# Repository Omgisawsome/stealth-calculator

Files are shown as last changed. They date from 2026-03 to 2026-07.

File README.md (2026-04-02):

Stealth Calculator- A Casio calculator with a Raspberry Pi put inside!

IMPORTANT NOTE FOR REVIEWERS, I ACCIDENTALLY PUT THIS AS TIER 2 WHEN IT'S A TIER 3 PROJECT THAT HAS A TOTAL COST OF $94.48 USD!

What is the project?

My stealth calculator is a calculator (Casio FX-991ESPLUS2), with the insides completely gutted out. Inside, it holds a Raspberry Pi Zero 2W as the main brain and a Raspberry Pi Pico 2 as a dedicated input controller. It utilizes matrix scanning to scan the custom PCB's rows and columns waiting for an input, and has the buttons mapped out. It has a 2.4 colour OLED touchscreen for easy usage and an integrated camera that's low profile, which allows the calculator to view the world, allowing for more functionality later on if I want to add other features.

How do I use it?

The device functions as a standard calculator, but by entering a special code (not sure what this will be I need to have the physical Pi to mess around with it), the user will switch from the standard Casio interface to a fully seperate menu. They may then use the integrated camera to take a photo of a math problem to recieve homework help, which is processed via the Gemini AI API to send the answers back to the calculator. It has built in WIFI, so to use at school you can just connect to your phone's hotspot for the best connection. It also constantly pulls updates from the repo, so you just need to clone it once, then it will update every few minutes (or longer depending if you want my new feature releases).

How do you build this yourself?

Just order all the parts on my BOM, and also order the PCB files. Unscrew open the calculator, and you will be able to lift off the board and the attached screen.

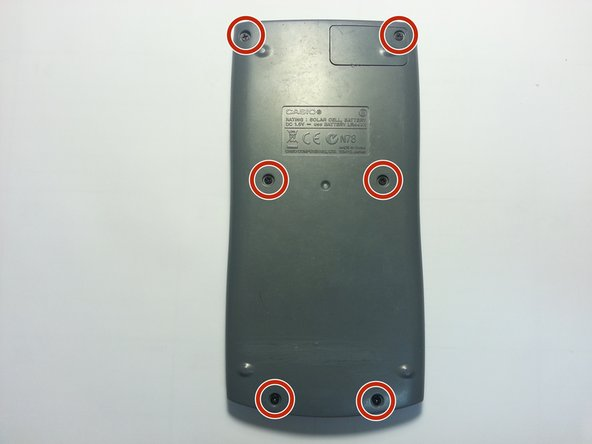
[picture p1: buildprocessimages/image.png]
Screws

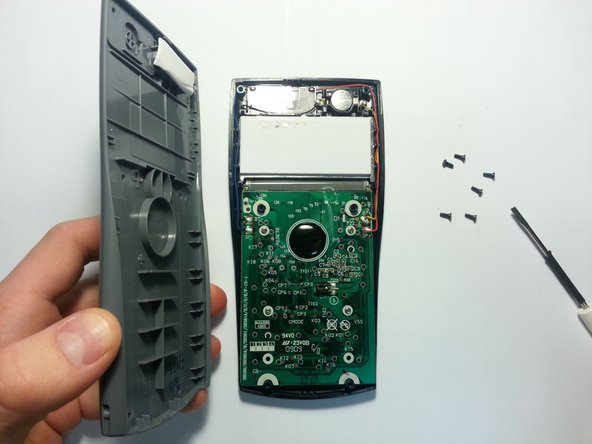
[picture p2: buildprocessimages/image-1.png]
Open Back Cover


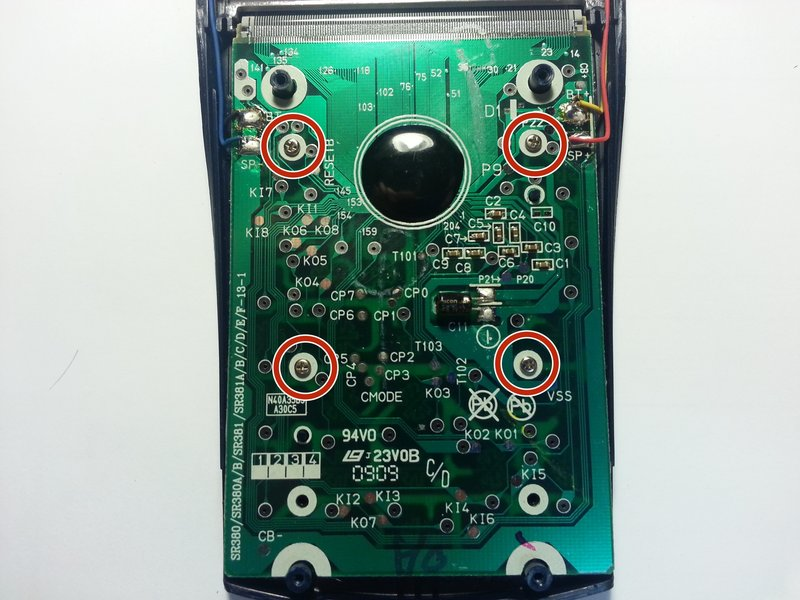
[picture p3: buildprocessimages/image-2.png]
Remove Plastic Pieces


In the calculator found in the BOM (these photos are from the web), the circled screws are actually hard pieces of plastic you have to snap. Aggresively pry the board out without breaking anything below (snap the board idc).

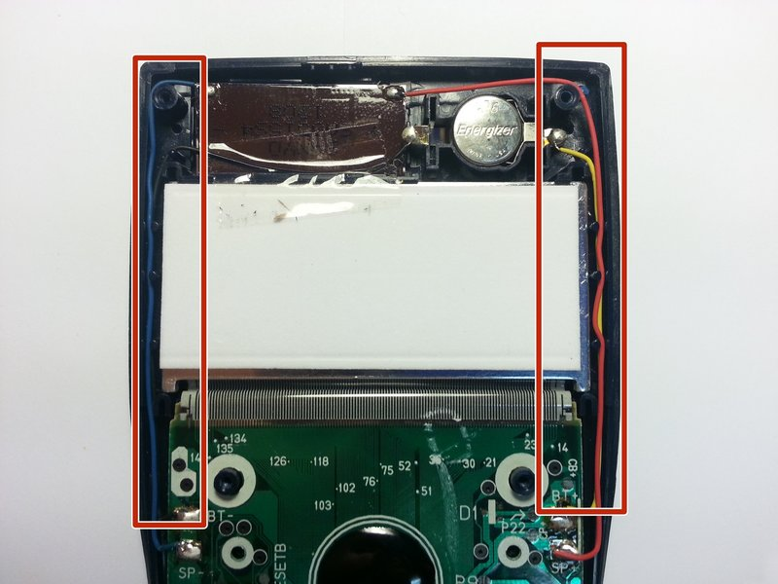
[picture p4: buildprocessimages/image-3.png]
Yank out all the guts


I really don't care if you break the PCB or screen or anything, just make sure to save this conductive rubber pad:

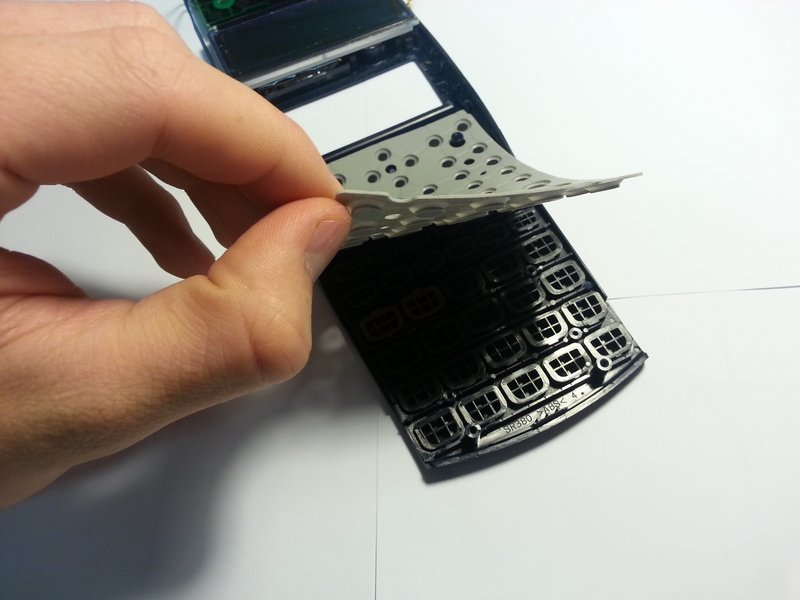
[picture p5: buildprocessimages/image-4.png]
Pad


Oh also make sure the buttons don't fall out that will irritate you (I did this myself it's so annoying).

All that should be saved is the solar panel from the top (to glue back in place), the buttons, the pad, and the top shell half and bottom shell half.

Your parts should look something like this (don't lose the screws like I did)

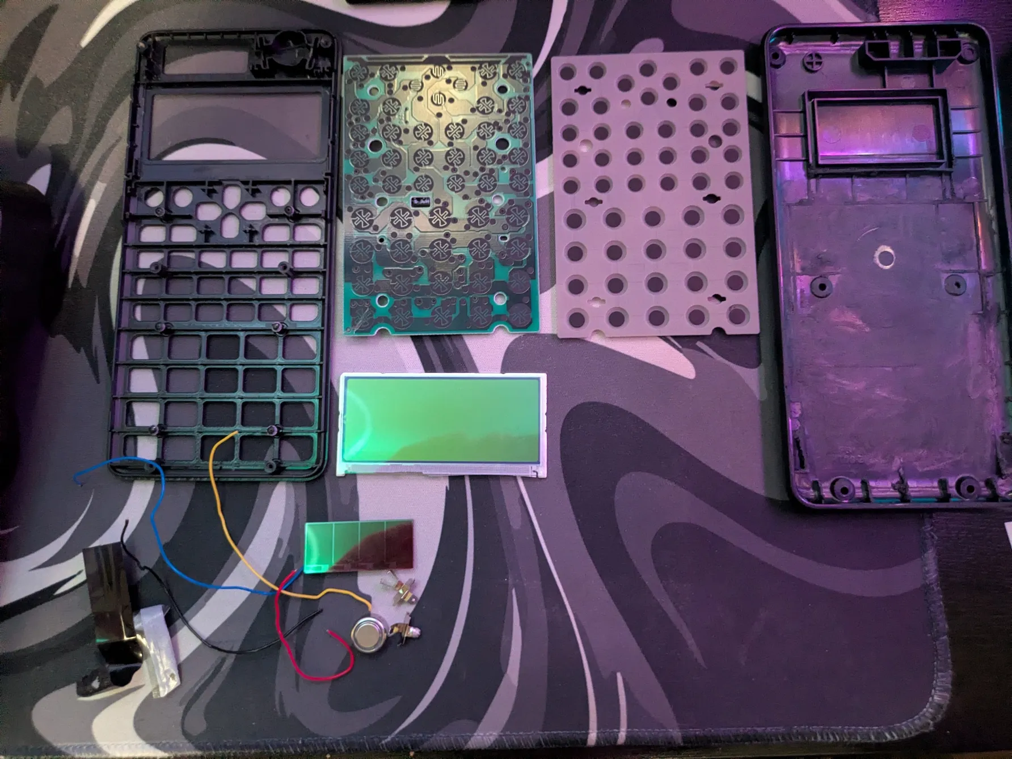
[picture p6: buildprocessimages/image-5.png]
Parts!


In the back of the calculator there's plastic parts, you will need to use a smal rotating saw or a mechanical sander to hollow out the shell, make sure not to touch other parts of the back shell and use this reference image:

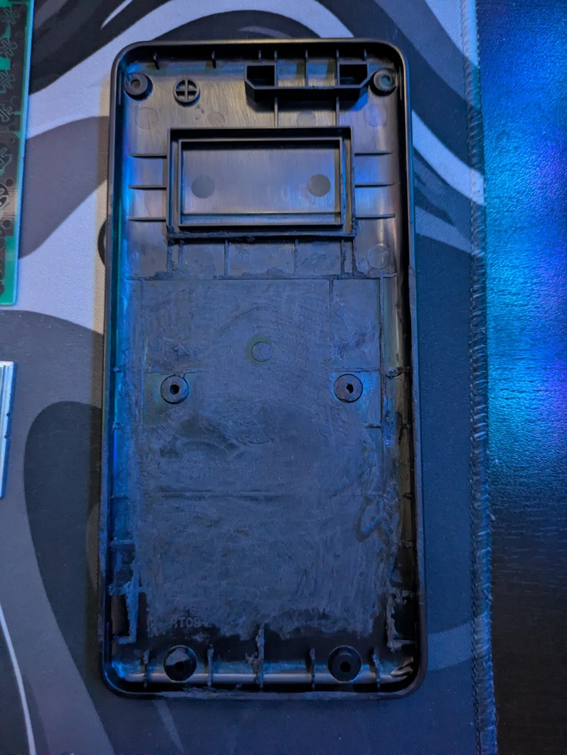
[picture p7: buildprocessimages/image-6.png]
Back panel hollowed out!


I haven't done these steps yet but when I get the parts it should go something like this:

SOFTWARE:
SET UP PI WITH MY REPO (CLONE IT)
Install screen drivers: Follow these steps: https://www.lcdwiki.com/2.4inch_RPi_Display_For_RPi_3A+#How_to_use_with_Raspberry_Pi_OS

1. Solder the battery to the boost board battery terminals, and the outputs to the Pi Zero 2W according to the schematic.
2. Desolder the hat attached to the screen, and then solder wires from the pins on the screen to the Pi Zero 2W.
3. Then solder all the row and column pads from the PCB to the Pico and solder the Pico to the Pi Zero 2W (again follow schematic).
4. Place screen where it belongs, glue in place and put the battery flat on top near the bottom (it's thin and long and wide).
5. Make sure both Pis do not touch any metal parts so they don't get short circuited (use heat resistance tape).
6. The repo should update and pull my code, I'm going to perfect it once I get the parts.

Why did I make this?
I just chose to make this because it turns out it's REALLY hard to do this without having extensive PCB design knowledge. To cram that many parts inside is insane when you're not making an all in one PCB. It's various components that you need to carefully account for in terms of space.

FINAL PICTURES:

Here are two copies of my schematic:
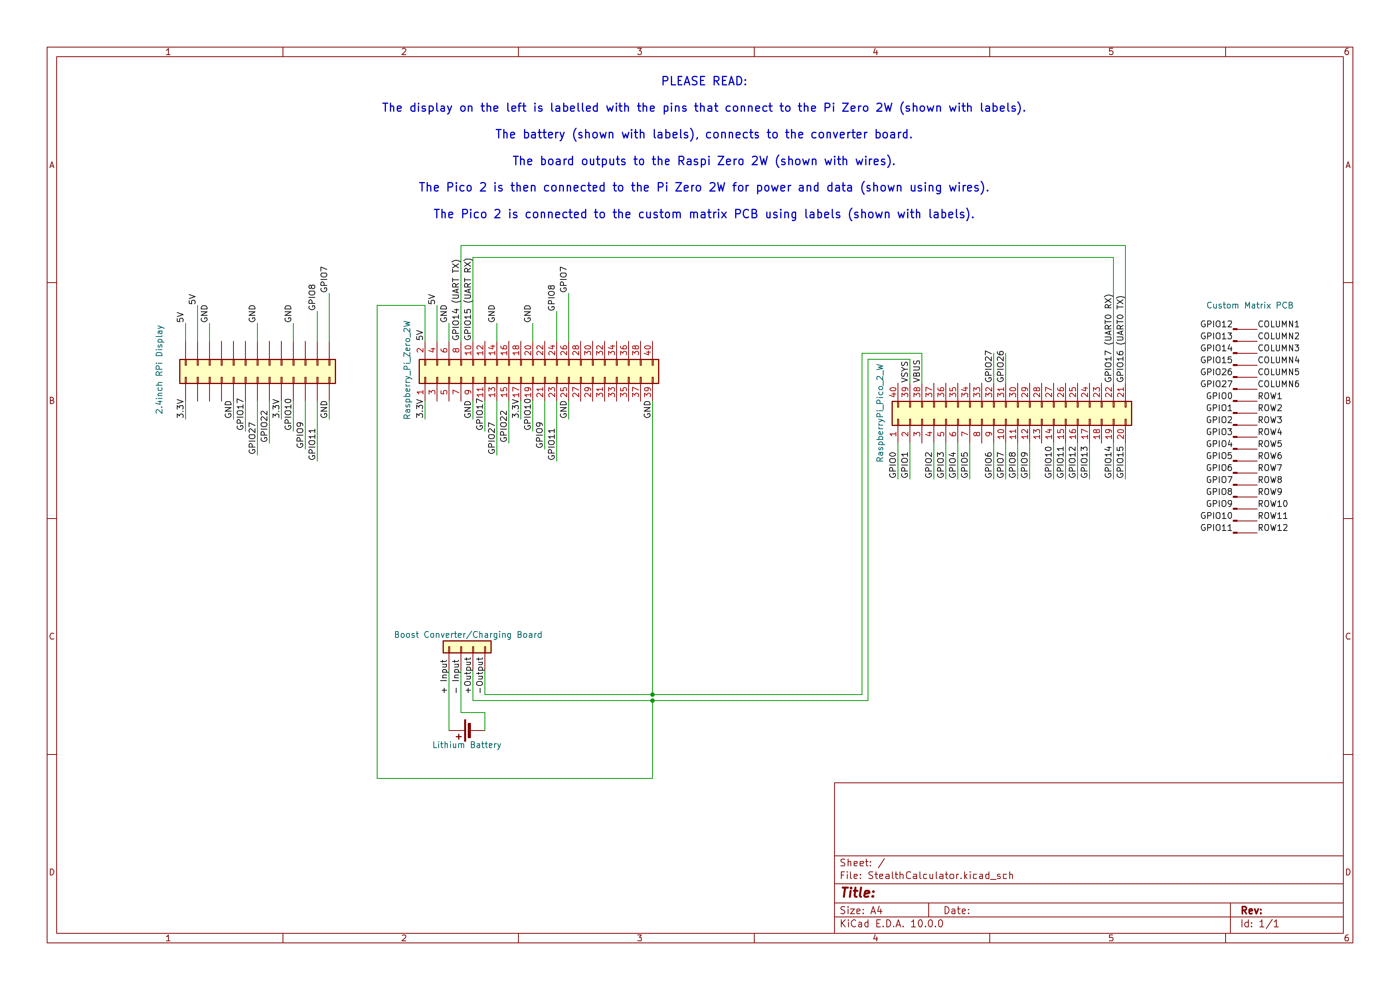
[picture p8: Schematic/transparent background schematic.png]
SchematicTransparent

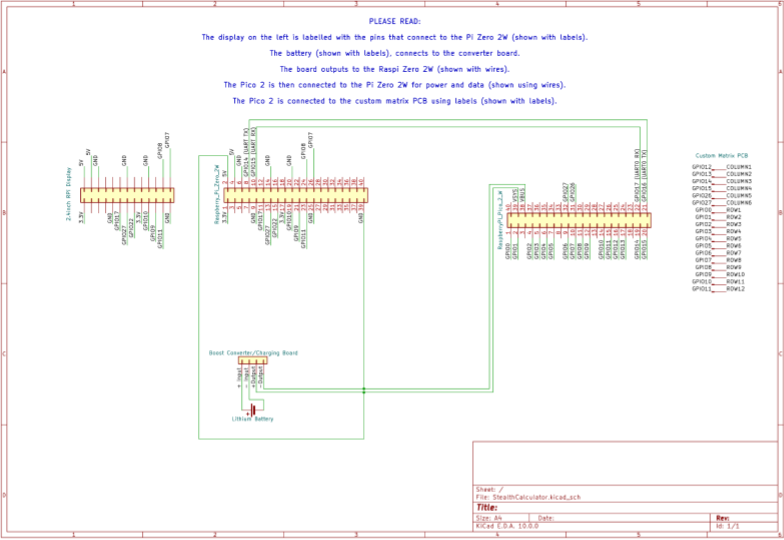
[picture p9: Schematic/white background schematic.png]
SchematicWhiteBackground


PCB DESIGN:

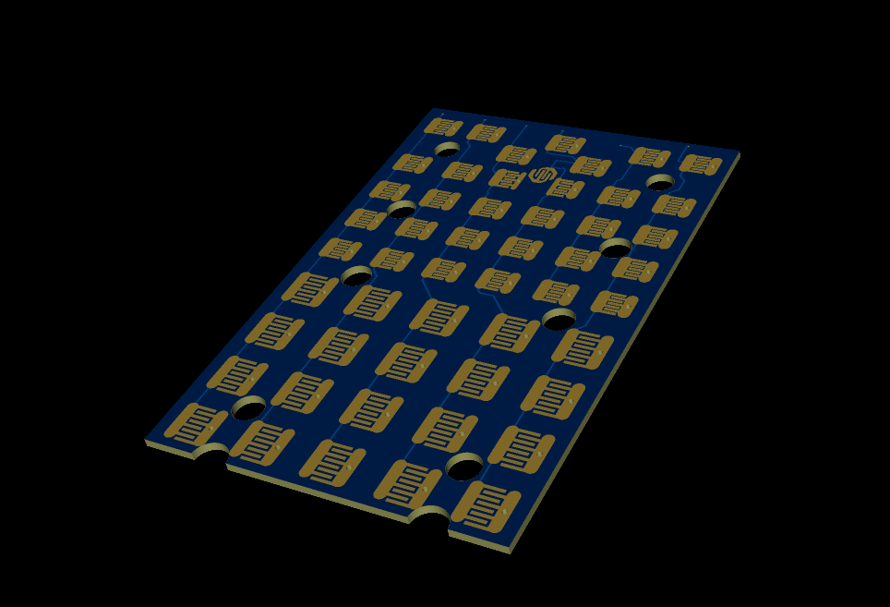
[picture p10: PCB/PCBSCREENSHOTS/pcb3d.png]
3D PCB VIEW


PCB ROWS AND COLUMNS:

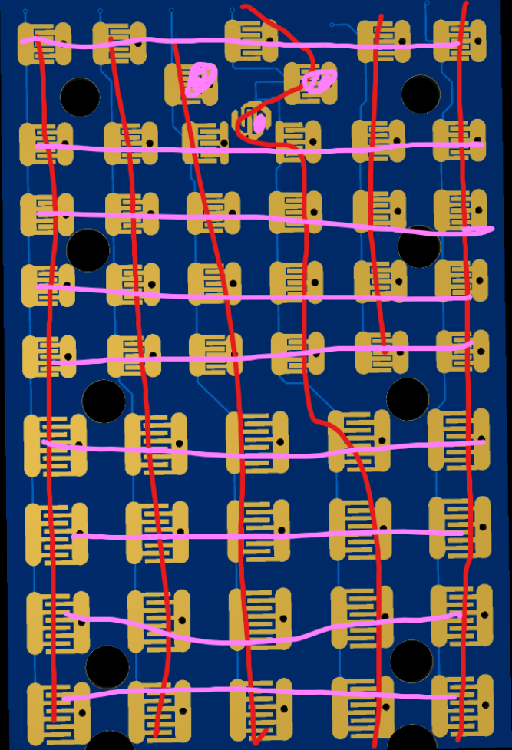
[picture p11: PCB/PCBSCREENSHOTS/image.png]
PCB ROWS AND COLUMNS


Matching Calculator Rows and Columns:

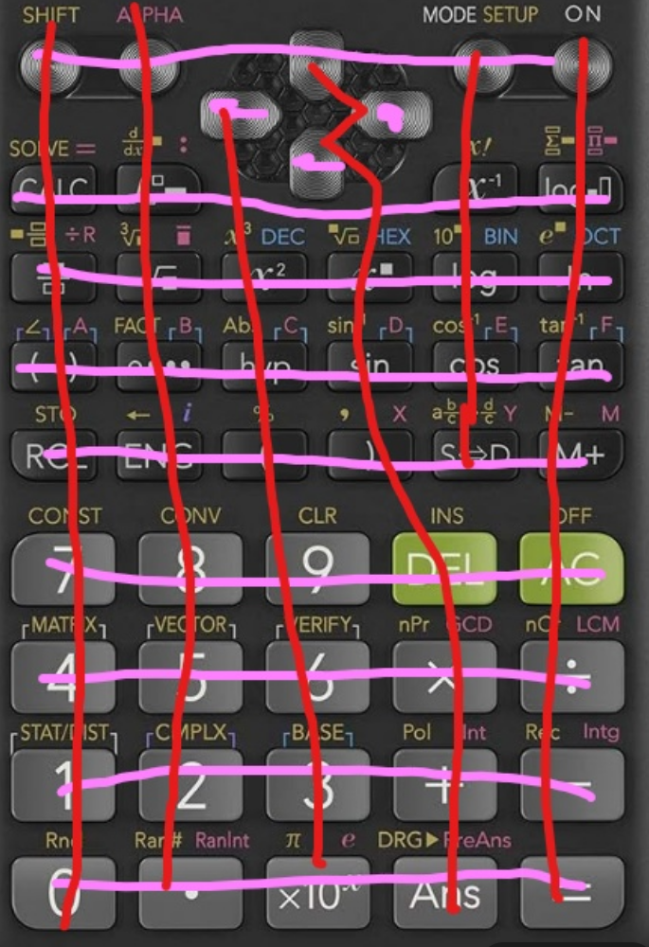
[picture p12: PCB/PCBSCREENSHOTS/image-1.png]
Matching Calculator Rows and Columns


IMPORTANT!!! HERE ARE THE COLUMN AND ROW LABELS!!!!

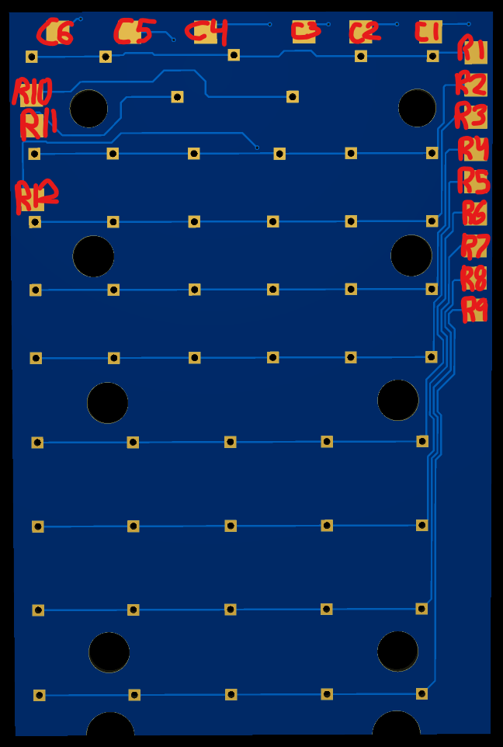
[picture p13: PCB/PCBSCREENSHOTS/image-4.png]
PAD LABELS


Here's the column (C) and row (R) labels, to follow the schematic diagram when wiring to the Pico.

PCB FRONT VIEW

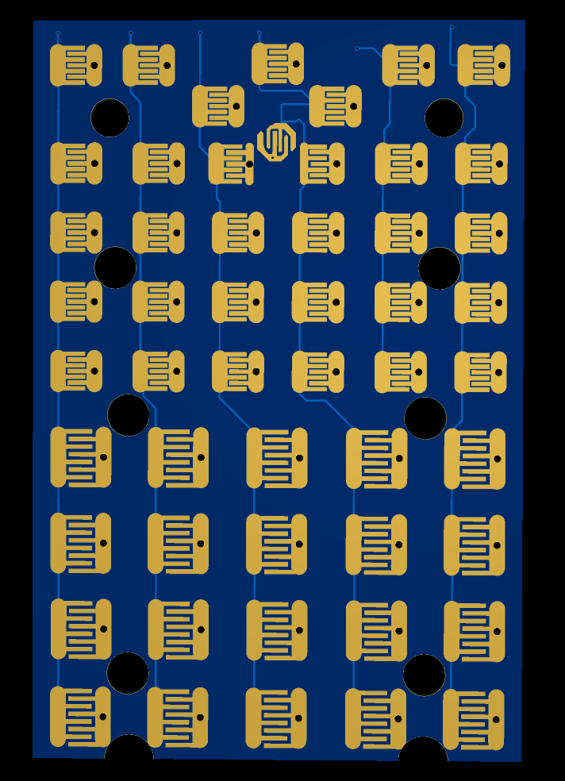
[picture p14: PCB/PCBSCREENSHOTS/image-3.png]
FRONTPCB


PCB BACK VIEW

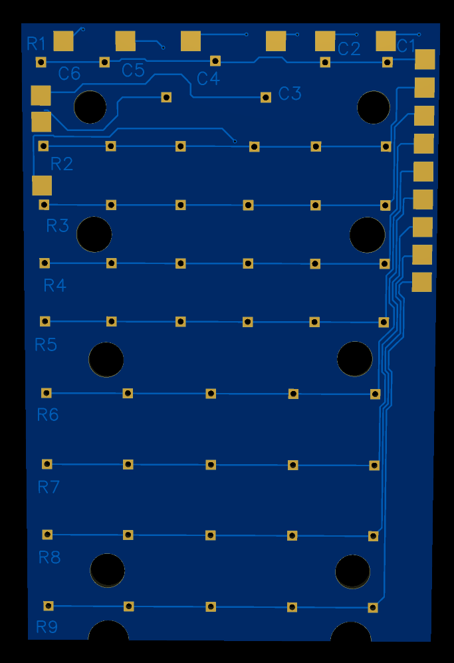
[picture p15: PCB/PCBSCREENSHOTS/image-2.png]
BACKPCB


Features that are currently planned as soon as I get the parts:
-PDF and Image viewer.
-RetroPie abilities for Games.
-Camera with a button that automatically takes a picture and sends the request to Gemini saying answer this, then the response is sent back and display on the screen.

Tell me more features to add!!!!
As of March 31, 2026 the firmware should be useable, but will be modified with features once the parts are obtained!!! I may need to adjust the matrix scanning slightly but until then, it's good!

Thanks for reading, stay tuned for the build!

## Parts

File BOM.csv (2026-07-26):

Item | Description | Quantity | Unit Price ($) | Total Price ($) | Running Total ($ with Tax) | URL | Status (Purchased or not)
Casio FX-991ESPLUS2 | Standard calculator, to be used as a shell to make it look like an original. | 1 | $25.97 | $25.97 | $25.97x1.13=$29.35 | https://www.amazon.ca/gp/product/B086548F31?smid=A3DWYIK6Y9EEQB&th=1&tag=operapc-def-sp-co2-ca-20 | Yes-I'M COVERING THE COST
2.4 Inch Touch Screen | A 2.4 inch touchscreen display to replace the original calculator screen. | 1 | $2.81 | $2.81 | $2.81 | https://www.aliexpress.com/item/1005005770033042.html | Yes-I'M COVERING THE COST
PCB Board | Custom PCB that has pads that can be wired to the Pi instead of just hooking up to the OG calculator screen. | 1 | $2.78 | $2.78 | 2.78+2.08+0.69=$5.55 | Custom PCB no URL | No
Raspberry Pi Zero 2 W | The main computer which is just powerful enough to run Linux and I can program it how I want, to act as a normal calculator and enter the secret menu. It has included wifi to constantly pull updates. | 1 | $32.99 | $32.99 | $32.99 x 1.13 = $37.28 | https://www.amazon.ca/gp/product/B09LH5SBPS?smid=A7SPEHY58ZFQP&psc=1 | No
Raspberry Pi Pico 2 | Input controller for the various row and column pads from the PCB, since I'd run out of pins on the Pi Zero 2 W. | 1 | $12.24 | $12.24 | $12.24 x 1.13 = $13.83 | https://www.aliexpress.com/item/1005008058623788.html?pdp_ext_f=%7B"order"%3A"1868"%2C"eval"%3A"1"%2C"fromPage"%3A"search"%7D&pdp_npi=6%40dis%21CAD%2110.86%2110.78%21%21%2152.57%2152.18%21%402103129017750139339438014e8990%2112000043493583247%21sea%21CA%217345587303%21X%211%210%21n_tag%3A-29911%3Bd%3A32857316%3Bm03_new_user%3A-29895&curPageLogUid=H1apDdqyqaUv&utparam-url=scene%3Asearch%7Cquery_from%3A%7Cx_object_id%3A1005008058623788%7C_p_origin_prod%3A | No
32GB MicroSD Card | Storage for Pi Zero 2W. | 1 | $7.19 | $7.19 | $7.19 x 1.13 = $8.12 | https://www.aliexpress.com/item/1005003194700801.html?pdp_ext_f=%7B"order"%3A"4789"%2C"spu_best_type"%3A"price"%2C"eval"%3A"1"%2C"fromPage"%3A"search"%7D&pdp_npi=6%40dis%21CAD%216.02%216.02%21%21%214.23%214.23%21%40210328c017750141131382936e1815%2112000024603441447%21sea%21CA%217345587303%21X%211%210%21n_tag%3A-29911%3Bd%3A32857316%3Bm03_new_user%3A-29895&curPageLogUid=LDJwuRYe7xny&utparam-url=scene%3Asearch%7Cquery_from%3A%7Cx_object_id%3A1005003194700801%7C_p_origin_prod%3A | No
Camera Module | Small camera for Pi. | 1 | $8.49 | $8.49 | $8.49 x 1.13 = $9.59 | https://www.aliexpress.com/item/32782501654.html?pdp_ext_f=%7B"order"%3A"1260"%2C"eval"%3A"1"%2C"fromPage"%3A"search"%7D&pdp_npi=6%40dis%21CAD%218.19%218.19%21%21%2139.64%2139.64%21%402101d9ef17750141550255414ec1fb%2112000031524996157%21sea%21CA%217345587303%21X%211%210%21n_tag%3A-29911%3Bd%3A32857316%3Bm03_new_user%3A-29895&curPageLogUid=r5m8JU2qXmXv&utparam-url=scene%3Asearch%7Cquery_from%3A%7Cx_object_id%3A32782501654%7C_p_origin_prod%3A | No
Lithium Polymer Battery | Battery to power the entire calculator. | 1 | $5.79 | $5.79 | $5.79 x 1.13 = $6.54 | https://www.aliexpress.com/item/32615585474.html?mp=1 | No
30 AWG PTFE Plastic Ultra Fine Wire | Super thin wire to solder with. | 1 | $2.44 | $2.44 | $2.44 x 1.13 = $2.76 | https://www.aliexpress.com/item/1005005454857771.html?mp=1 | No
M.2 Screw Kit | An assortment of screws to use on the back of the calculator. | 1 | $5.89 | $5.89 | $5.89 x 1.13 = $6.66 | https://www.aliexpress.com/item/1005007399285653.html?pdp_ext_f=%7B"order"%3A"2205"%2C"spu_best_type"%3A"price"%2C"eval"%3A"1"%2C"fromPage"%3A"search"%7D&pdp_npi=6%40dis%21CAD%215.81%215.40%21%21%214.08%213.79%21%402101d6fe17750143509683372ea280%2112000040585391783%21sea%21CA%217345587303%21X%211%210%21n_tag%3A-29911%3Bd%3A32857316%3Bm03_new_user%3A-29895&curPageLogUid=8C0BroRNViuz&utparam-url=scene%3Asearch%7Cquery_from%3A%7Cx_object_id%3A1005007399285653%7C_p_origin_prod%3A | No
Kapton Tape (10mm Width) | Insulating tape that can't melt to prevent short circuiting. | 1 | $4.76 | $4.76 | $4.76 x 1.13 = $5.38 | https://www.aliexpress.com/item/1005004225392537.html?mp=1 | No
Type-C USB 5V 2A Boost Converter | To charge the battery and safely connect it to the Pi. | 1 | $3.89 | $3.89 | $3.89 x 1.13 = $4.40 | https://www.aliexpress.com/item/1005011961215291.html?mp=1 | No
Interruptor on-off mini Slide Switch 3pin | Main power switch to turn it on and off. | 1 | $3.51 | $3.51 | $3.51 x 1.13 = $3.97 | https://www.aliexpress.com/item/1005007162182882.html?mp=1&pdp_ext_f=%7B"cart2PdpParams"%3A%7B"pdpBusinessMode"%3A"retail"%7D%7D | No
 |  |  |  | PRICES CHANGE BUT I KEEP THIS UP TO DATE:
 |  |  |  | Total Cost | C$74.60 (Shipping included)
 |  |  |  | Final Cost USD | $52.60 USD

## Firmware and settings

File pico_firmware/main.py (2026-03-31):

import machine
import time

ROWS = [0, 1, 2, 3, 4, 5, 6, 7, 8, 9, 10, 11]


COLS = [12, 13, 14, 15, 26, 27]


uart = machine.UART(1, baudrate=9600, tx=machine.Pin(20), rx=machine.Pin(21))

# KEYBOARD MAP

KEY_MAP = {
    "R1C1": "SHIFT", "R1C2": "ALPHA", "R1C3": "UP", "R1C5": "MODE", "R1C6": "ON",
    "R2C1": "LEFT", "R3C1": "RIGHT", "R4C1": "DOWN",
    "R5C1": "CALC", "R5C2": "INTEGRAL", "R5C3": "X_INV", "R5C4": "LOG_B",
    "R6C1": "FRAC", "R6C2": "SQRT", "R6C3": "X_SQR", "R6C4": "X_POW", "R6C5": "LOG", "R6C6": "LN",
    "R7C1": "NEG", "R7C2": "TIME", "R7C3": "HYP", "R7C4": "SIN", "R7C5": "COS", "R7C6": "TAN",
    "R8C1": "RCL", "R8C2": "ENG", "R8C3": "L_BRACKET", "R8C4": "R_BRACKET", "R8C5": "SD", "R8C6": "M_PLUS",
    "R9C1": "7", "R9C2": "8", "R9C3": "9", "R9C4": "DEL", "R9C5": "AC",
    "R10C1": "4", "R10C2": "5", "R10C3": "6", "R10C4": "MULT", "R10C5": "DIV",
    "R11C1": "1", "R11C2": "2", "R11C3": "3", "R11C4": "PLUS", "R11C5": "MINUS",
    "R12C1": "0", "R12C2": "DOT", "R12C3": "EXP", "R12C4": "ANS", "R12C5": "EQUAL"
}


row_pins = [machine.Pin(p, machine.Pin.OUT) for p in ROWS]
col_pins = [machine.Pin(p, machine.Pin.IN, machine.Pin.PULL_DOWN) for p in COLS]

def scan_matrix():
    for r_idx, r_pin in enumerate(row_pins):
        r_pin.value(1)  
        for c_idx, c_pin in enumerate(col_pins):
            if c_pin.value() == 1:

                code = f"R{r_idx+1}C{c_idx+1}"
                label = KEY_MAP.get(code, "UNUSED")
                
                uart.write(label + "\n")
                print(f"Sent to Pi: {label}")

                while c_pin.value() == 1:
                    time.sleep(0.05)
        r_pin.value(0)


print("Stealth Calc Matrix Engine: ONLINE")
while True:
    scan_matrix()
    time.sleep(0.01)

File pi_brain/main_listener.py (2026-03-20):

import serial
import subprocess
import os
import time
from gemini_vision import solve_math  

SECRET_CODE = ["4", "1", "6", "7"]
input_history = []
mode = "CALC" # Modes: CALC, MENU, GEMINI, PDF, GAME

# PICO CONNECTIVITY
ser = serial.Serial('/dev/ttyAMA0', 9600, timeout=1)

def launch_game():
    print("Launching RetroPie...")
    # EmulationStation
    subprocess.run(["sudo", "systemctl", "start", "emulationstation"])

def open_pdf(filename):
    print(f"Opening {filename}...")
    subprocess.run(["python3", "pdf_viewer.py", filename])

def handle_key(key):
    global mode, input_history
    
    if mode == "CALC":
        input_history.append(key)
        if input_history[-4:] == SECRET_CODE:
            mode = "MENU"
            print("--- SECRET MENU UNLOCKED ---")
            # Logic to display menu on screen
        
    elif mode == "MENU":
        if key == "1": mode = "GEMINI"
        if key == "2": launch_game()
        if key == "3": open_pdf("textbook.pdf")
        if key == "AC": mode = "CALC" # Emergency hide functionality

while True:
    if ser.in_waiting > 0:
        key_pressed = ser.readline().decode('utf-8').strip()
        handle_key(key_pressed)
    time.sleep(0.01)

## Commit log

2026-03-20 Added PICO inputs, Main Pi Functionality
2026-03-21 Added PCB source files
2026-03-31 sync pico firmware with hardware schematic and fix pin conflicts
    [main.py]
2026-03-31 Update column pin assignments and changed initialization message
2026-04-01 deleting blank BOM
2026-04-01 Upload up to date BOM
    [BOM.csv]
2026-04-02 New images, updated PCB GERBERS
2026-04-02 fix more formatting
    Added images and descriptions for PCB design and features.
2026-04-02 SCHEMATIC IMAGES ARE IN!
    [StealthCalculator.kicad_sch]
2026-04-04 NEW BOM
    [BOM.csv]
2026-07-22 New BOM for Macondo Submission
    [revilo- BOM For Stealth Calculator - Sheet1 (1).csv]
2026-07-22 Rename BOM
2026-07-26 Add new BOM
    [BOM.csv]
